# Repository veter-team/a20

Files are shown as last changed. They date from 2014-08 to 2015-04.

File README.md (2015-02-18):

a20
===

Robot for PiWars competition: http://piwars.org

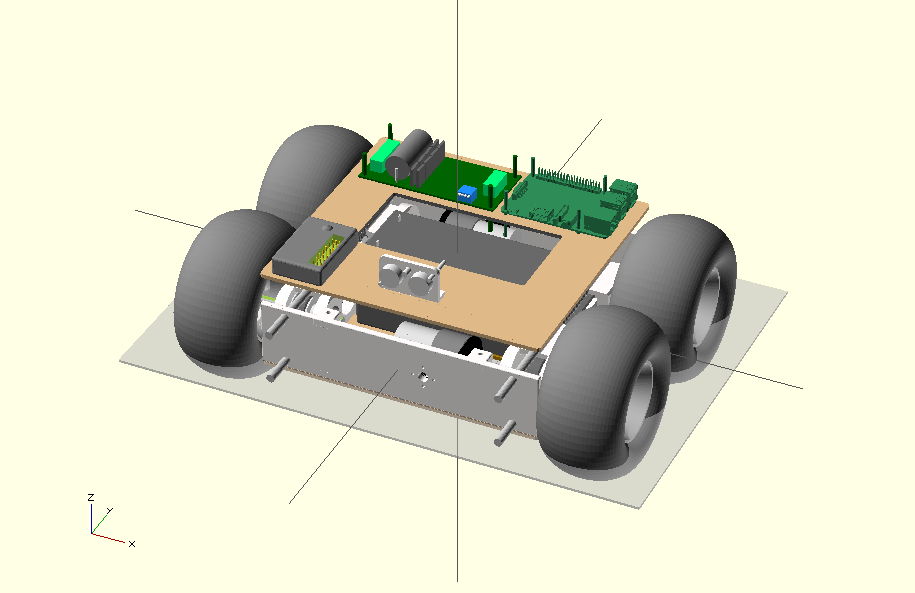
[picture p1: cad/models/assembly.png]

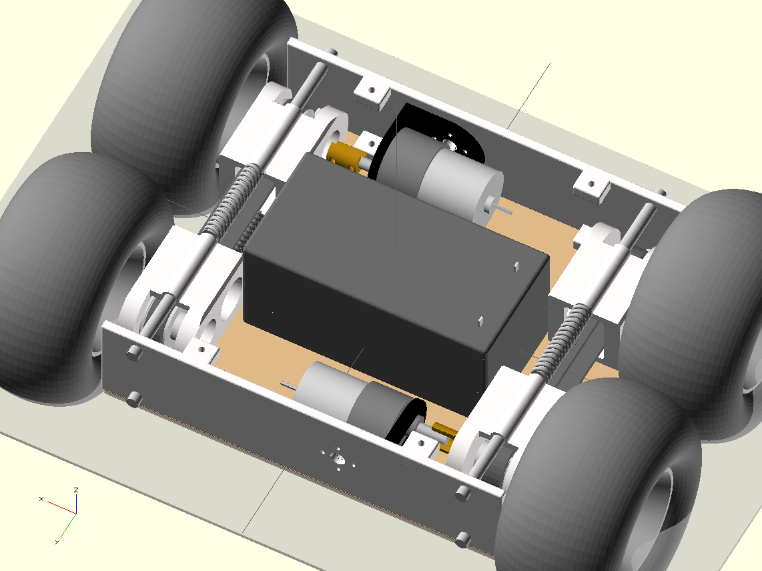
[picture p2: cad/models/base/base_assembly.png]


And here is the video of the first test-drive (RC-controlled): 
http://youtu.be/W47cyLSvp90

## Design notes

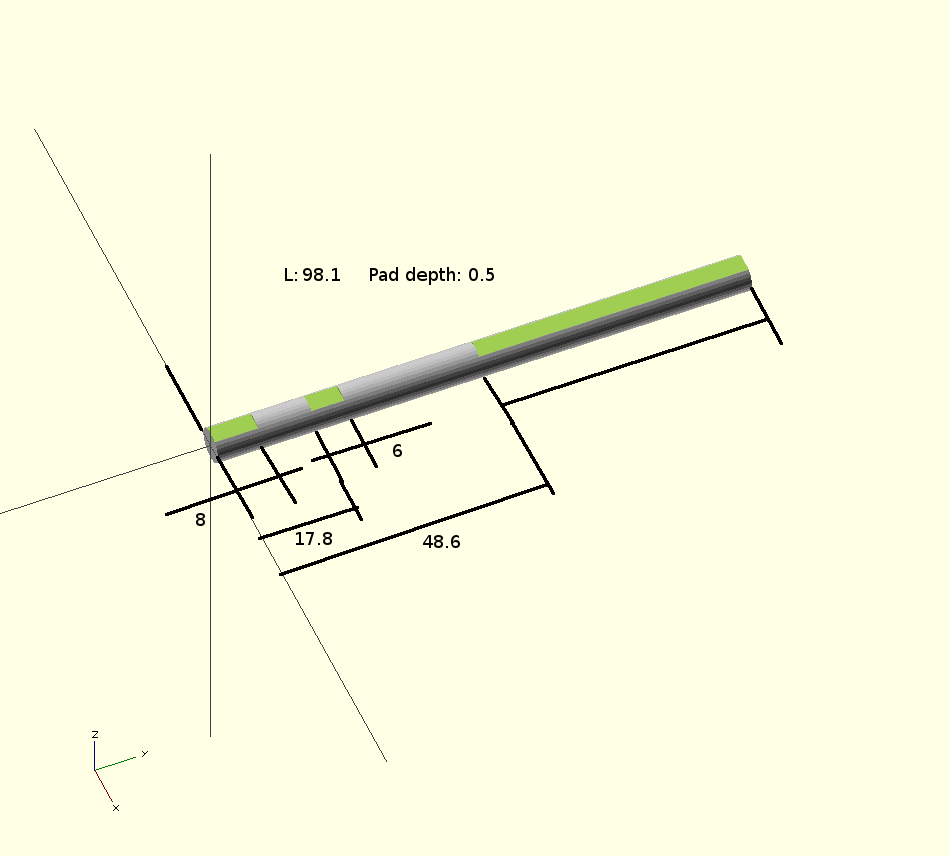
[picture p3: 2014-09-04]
cad/models/base/wheel_shaft.png

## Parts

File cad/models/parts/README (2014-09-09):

STL models of Raspberry Pi B+ are copied from here:
http://www.thingiverse.com/thing:402498/#files
They are included for convenience.

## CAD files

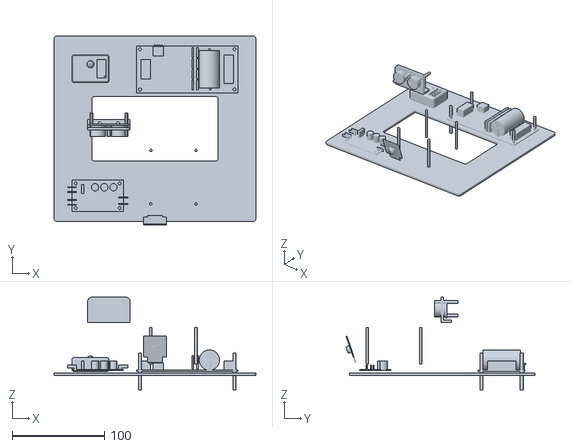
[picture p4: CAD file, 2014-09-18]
cad/models/deck2/stl/deck2_assembly.stl
219.2 x 205.4 x 100.8

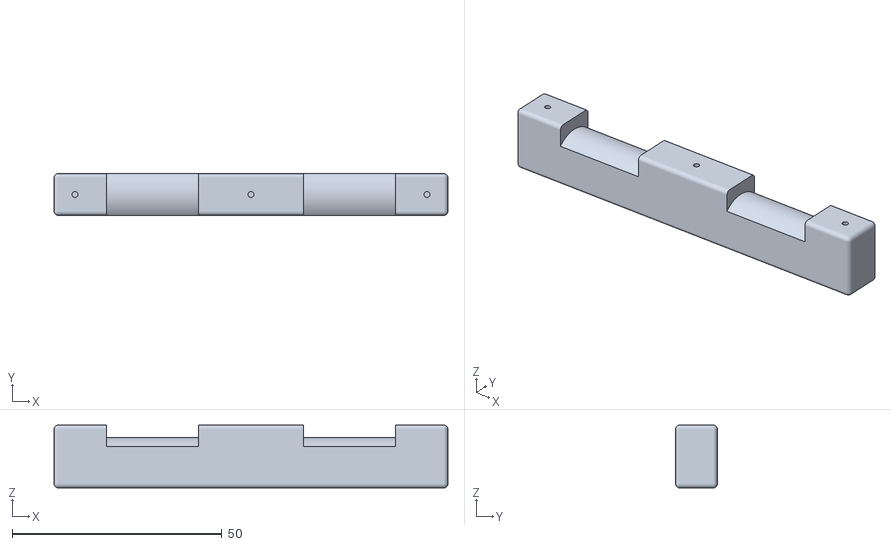
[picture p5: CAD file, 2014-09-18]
cad/for3dprint/base/bottom_battery_holder.stl
94.0 x 10.0 x 15.0

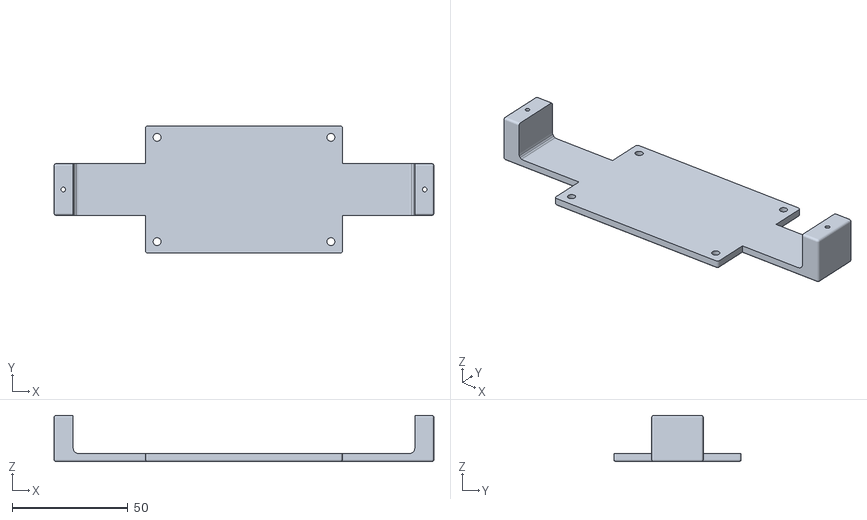
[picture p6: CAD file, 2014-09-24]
cad/for3dprint/deck2/iface_board_holder.stl
164.0 x 55.0 x 20.0

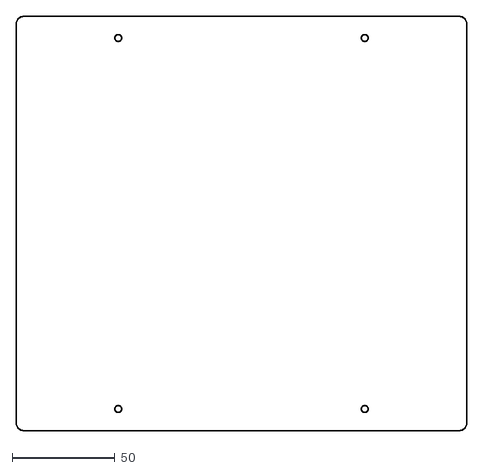
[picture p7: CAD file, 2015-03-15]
cad/forcutting/base1.dxf
219.2 x 201.6

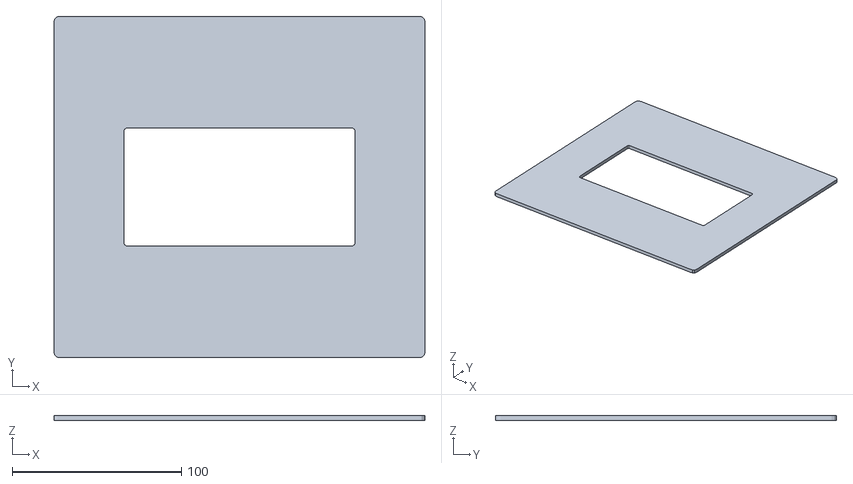
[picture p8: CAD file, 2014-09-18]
cad/models/base/stl/base2.stl
219.2 x 201.6 x 3.00

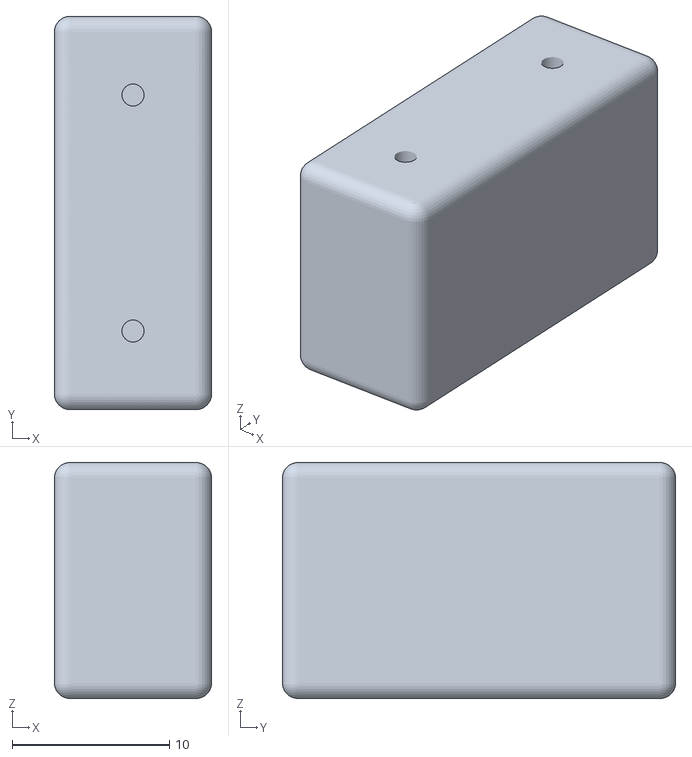
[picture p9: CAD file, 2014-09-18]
cad/for3dprint/base/bottom_battery_stopper.stl
10.0 x 25.0 x 15.0

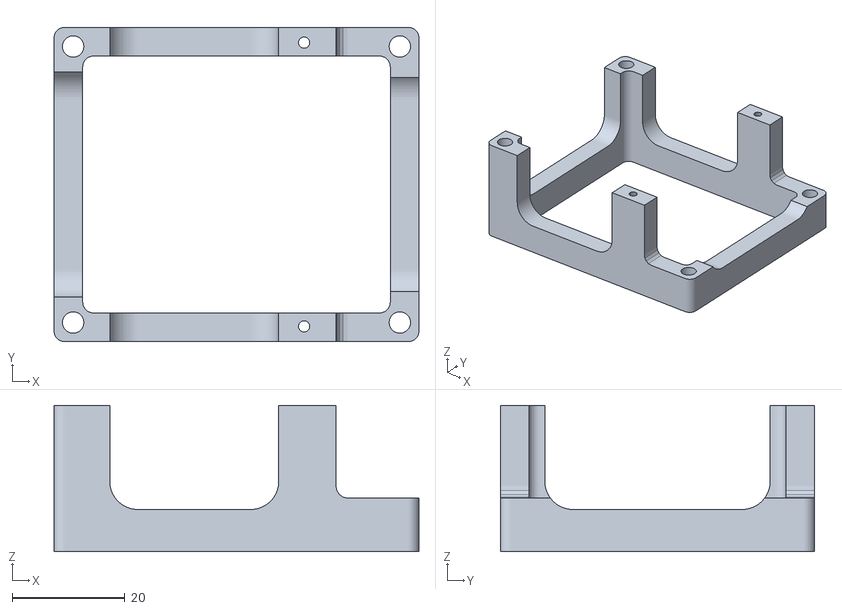
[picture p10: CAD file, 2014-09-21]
cad/for3dprint/deck2/rpi_holder.stl
64.8 x 55.8 x 26.0

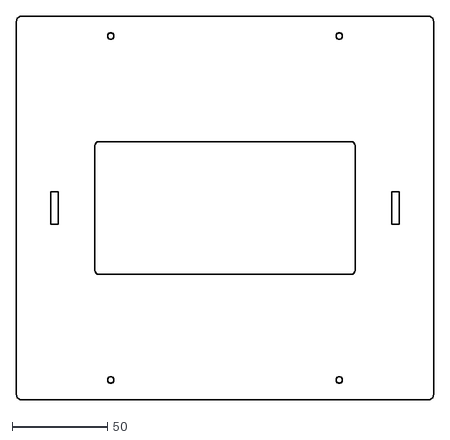
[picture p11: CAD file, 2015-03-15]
cad/forcutting/base2.dxf
219.2 x 201.6

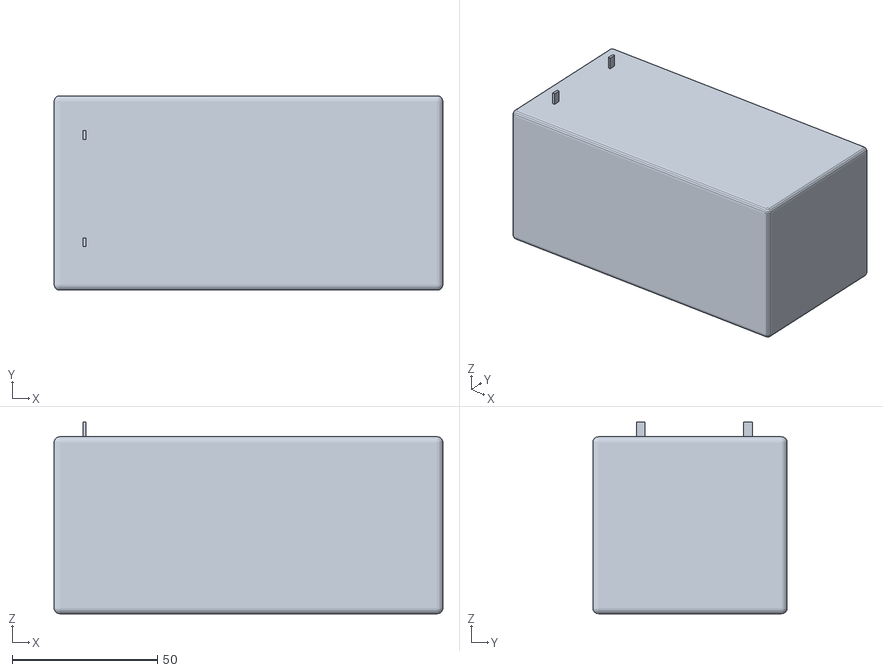
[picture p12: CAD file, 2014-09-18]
cad/models/base/stl/lead_battery.stl
134.0 x 67.0 x 66.0

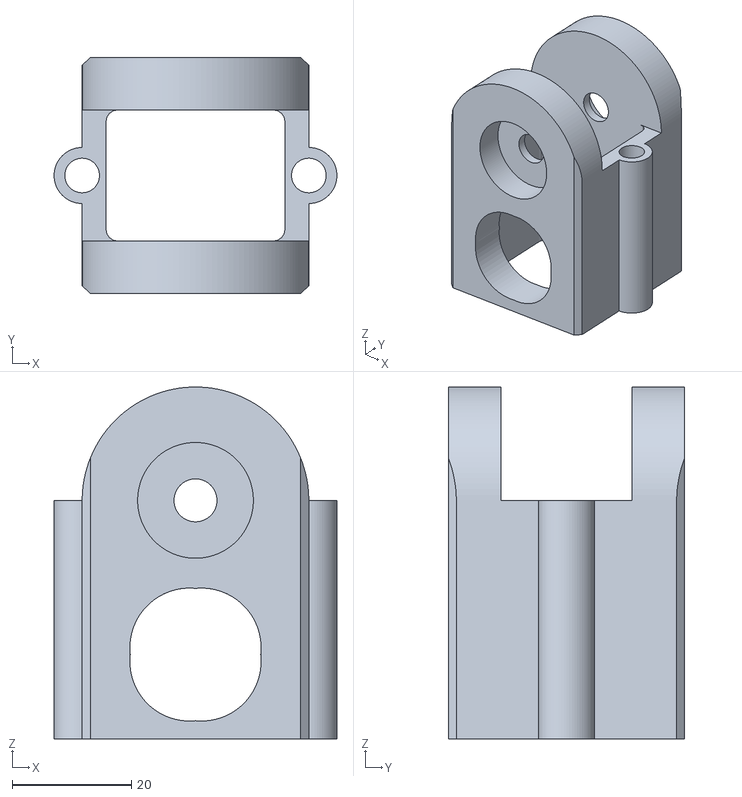
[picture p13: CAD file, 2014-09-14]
cad/for3dprint/base/wheel_holder.stl
47.4 x 39.6 x 59.0

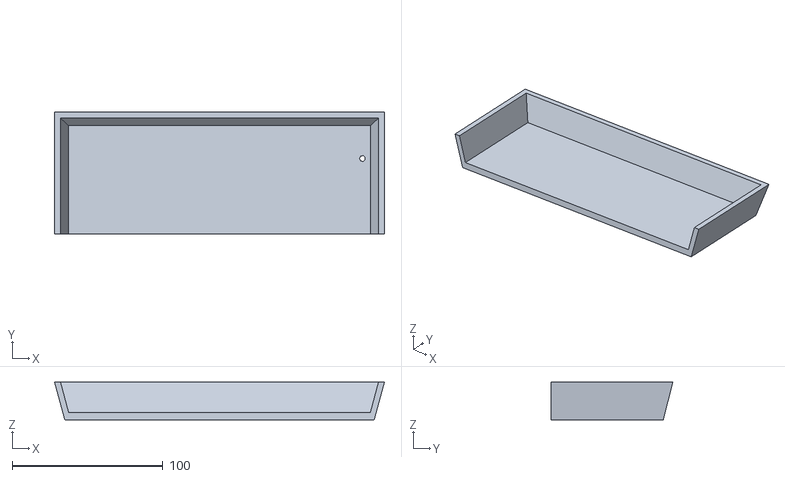
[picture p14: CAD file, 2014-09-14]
cad/for3dprint/deck2/cover2.stl
219.2 x 80.8 x 25.0

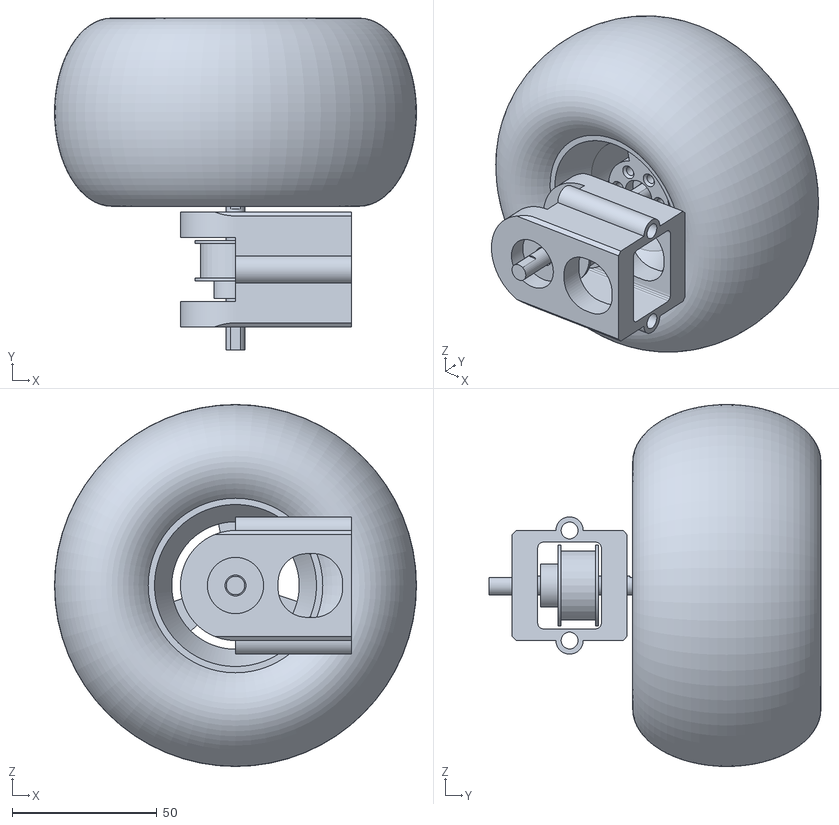
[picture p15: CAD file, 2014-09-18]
cad/models/base/stl/wheel_block.stl
125.0 x 114.6 x 125.0

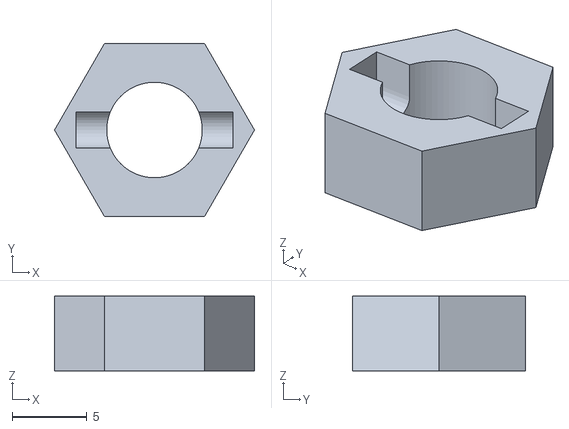
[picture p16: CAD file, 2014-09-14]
cad/for3dprint/base/wheel_clutch.stl
13.4 x 11.6 x 5.00

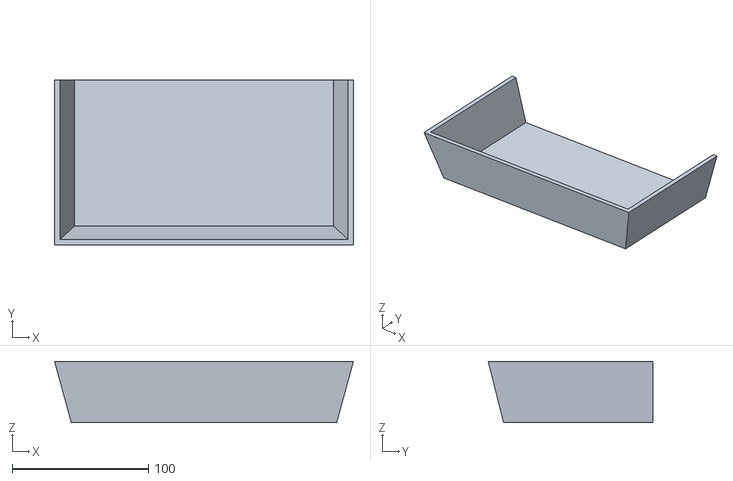
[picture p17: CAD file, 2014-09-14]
cad/for3dprint/deck2/cover1.stl
219.2 x 120.8 x 45.0

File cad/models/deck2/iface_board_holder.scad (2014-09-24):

use <../MCAD/boxes.scad>
include <../main_dimensions.scad>
use <../base/lead_battery.scad>

pad_x_dim = 85;
pad_y_dim = 55;
base_box_dim = [akku_x_dim + 30, akku_y_dim / 3, 20];


module m_hole()
{
    translate([pad_x_dim / 2 - 5, pad_y_dim / 2 - 5, base_box_dim[2] - 4.1])
    mounting_hole(5, false, $fn = 64);
}


module screw_hole()
{
    translate([base_box_dim[0] / 2 - 4, 0, -0.1])
    cylinder(r = 1, h = base_box_dim[2] + 0.3, $fn = 64);
}


module iface_board_holder()
{
    difference()
    {
        union()
        {
            translate([0, 0, 20 / 2])
            roundedBox(base_box_dim, 1, false, $fn = 64);
            
            translate([0, 0, 20 / 2])
            roundedBox([pad_x_dim, pad_y_dim, 20], 1, false, $fn = 64);
        }
        
        // Battery
        translate([0, 0,
                -wheel_holder_z_dim / 2 - shaft_radius - 2 + base_z_size / 2
                - (wheel_holder_z_dim / 2 + shaft_radius + 2 + base_z_size / 2 + 1)])
        scale([1.1, 1.04, 1.08])
        lead_battery();

        m_hole();
        mirror([0, 1, 0])
        m_hole();
        mirror([1, 0, 0])
        {
            m_hole();
            mirror([0, 1, 0])
            m_hole();
        }

        screw_hole();
        mirror([1, 0, 0])
        screw_hole();
    }
    
}


if(ASSEMBLY == undef || ASSEMBLY == 0)
{
    translate([0, 0, base_box_dim[2]])
    rotate([180, 0, 0])
    iface_board_holder();
}

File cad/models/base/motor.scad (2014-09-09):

include <../main_dimensions.scad>

// http://www.pololu.com/product/1442

module motor()
{
    motor_r1 = 36.8 / 2;
    motor_l1 = 22;
    motor_r2 = 33 / 2;
    motor_l2 = 30;

    // back shaft
    color("Silver")
    translate([0, 0, -motor_l1 - motor_l2 - 3 - 10])
    cylinder(h = 12, r = 2 / 2);
    // back shaft holder
    color("LightGray")
    translate([0, 0, -motor_l1 - motor_l2 - 3], $fn = 64)
    cylinder(h = 3, r = 9 / 2);
    // thin back part
    color("LightGray")
    translate([0, 0, -motor_l1 - motor_l2])
    cylinder(h = motor_l2, r = motor_r2, $fn = 128);
    // thick front part
    color("Gray")
    translate([0, 0, -motor_l1])
    cylinder(h = motor_l1, r = motor_r1, $fn = 128);
    translate([motor_shaft_shift, 0, 0])
    {
        // front shaft holder
        color("Gray")
        cylinder(h = 6.5, r = 6, $fn = 64);
        // front shaft
        color("Silver")
        cylinder(h = 22, r = 3, $fn = 64);
    }
}

if(ASSEMBLY == undef || ASSEMBLY == 0)
{
    motor();
}

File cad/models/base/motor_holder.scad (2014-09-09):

// MMT-03 motor holder
// http://www.lynxmotion.com/images/data/mmt-03.pdf

include <../main_dimensions.scad>

$fn = 64;


module motor_holder_mounting_holes(depth = 50)
{
    translate([24, motor_holder_y_dim / 2, 0])
    {
        cylinder(r = 3.9751, h = depth, center = true);

        for(i = [0 : 360 / 4 : 360])
        {
            rotate([0, 0, i])
            translate([0, 8.3312, 0])
            cylinder(r = 1.1938, h = depth, center = true);
        }
    }
}


module motor_holder()
{
    color("Black")
    translate([0, -motor_holder_y_dim / 2, 0])
    difference()
    {
        union()
        {
            cube([motor_holder_x_dim - motor_holder_y_dim / 2, motor_holder_y_dim, motor_holder_z_dim - motor_holder_y_dim / 2]);
            translate([motor_holder_x_dim - motor_holder_y_dim / 2, motor_holder_y_dim / 2, 0])
            cylinder(r = motor_holder_y_dim / 2, h = motor_holder_z_dim - motor_holder_y_dim / 2);

            translate([0, motor_holder_y_dim / 2, motor_holder_z_dim - motor_holder_y_dim / 2])
            rotate([0, 90, 0])
            cylinder(r = motor_holder_y_dim / 2, h = motor_holder_x_dim - motor_holder_x_dim / 2);
        }
        translate([motor_holder_h, -tolerance, motor_holder_h])
        cube([motor_holder_x_dim, motor_holder_y_dim + 2 * tolerance, motor_holder_z_dim]);

        // Shaft hole
        translate([motor_holder_h / 2, motor_holder_y_dim / 2, 25.0])
        union()
        {
            translate([-motor_holder_h, 0, -14.3 / 2])
            rotate([0, 90, 0])
            cylinder(r = 13 / 2, h = 2 * motor_holder_h);

            cube([2 * motor_holder_h, 13, 14.3], center = true);

            translate([-motor_holder_h, 0, 14.3 / 2])
            rotate([0, 90, 0])
            cylinder(r = 13 / 2, h = 2 * motor_holder_h);
        }

        // Motor mounting holes
        translate([motor_holder_h / 2, motor_holder_y_dim / 2, 25.0])
        for(i = [0 : 360 / 6 : 360])
        {
            rotate([i, 0, 0])
            translate([0, 31 / 2, 0])
            rotate([0, 90, 0])
            cylinder(r = 3.3 / 2, h = 50, center = true);
        }

        motor_holder_mounting_holes(3 * motor_holder_h);
    }
}

if(ASSEMBLY == undef || ASSEMBLY == 0)
{
  motor_holder();
}

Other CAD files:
cad/models/base/stl/base1.stl
cad/for3dprint/base/front_pannel.stl
cad/models/base/wheel.scad
cad/models/BezierScad.scad
cad/models/MCAD/boxes.scad
cad/models/MCAD/involute_gears.scad
cad/models/MCAD/metric_fastners.scad
cad/models/MCAD/regular_shapes.scad
cad/models/accessories/ball_collector.scad
cad/models/accessories/ball_collector/assembly.scad
cad/models/accessories/ball_collector/ball_collector.scad
cad/models/accessories/ball_collector/ball_collector_blade.scad
cad/models/accessories/ball_collector/bearing_cover.scad
cad/models/accessories/ball_collector/bearing_stopper.scad
cad/models/accessories/ball_collector/blade_middle.scad
cad/models/accessories/ball_collector/blade_motor_side.scad
cad/models/accessories/ball_collector/blade_nomotor_side.scad
cad/models/accessories/ball_collector/cone_gear.scad
cad/models/accessories/ball_collector/motor_box.scad
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

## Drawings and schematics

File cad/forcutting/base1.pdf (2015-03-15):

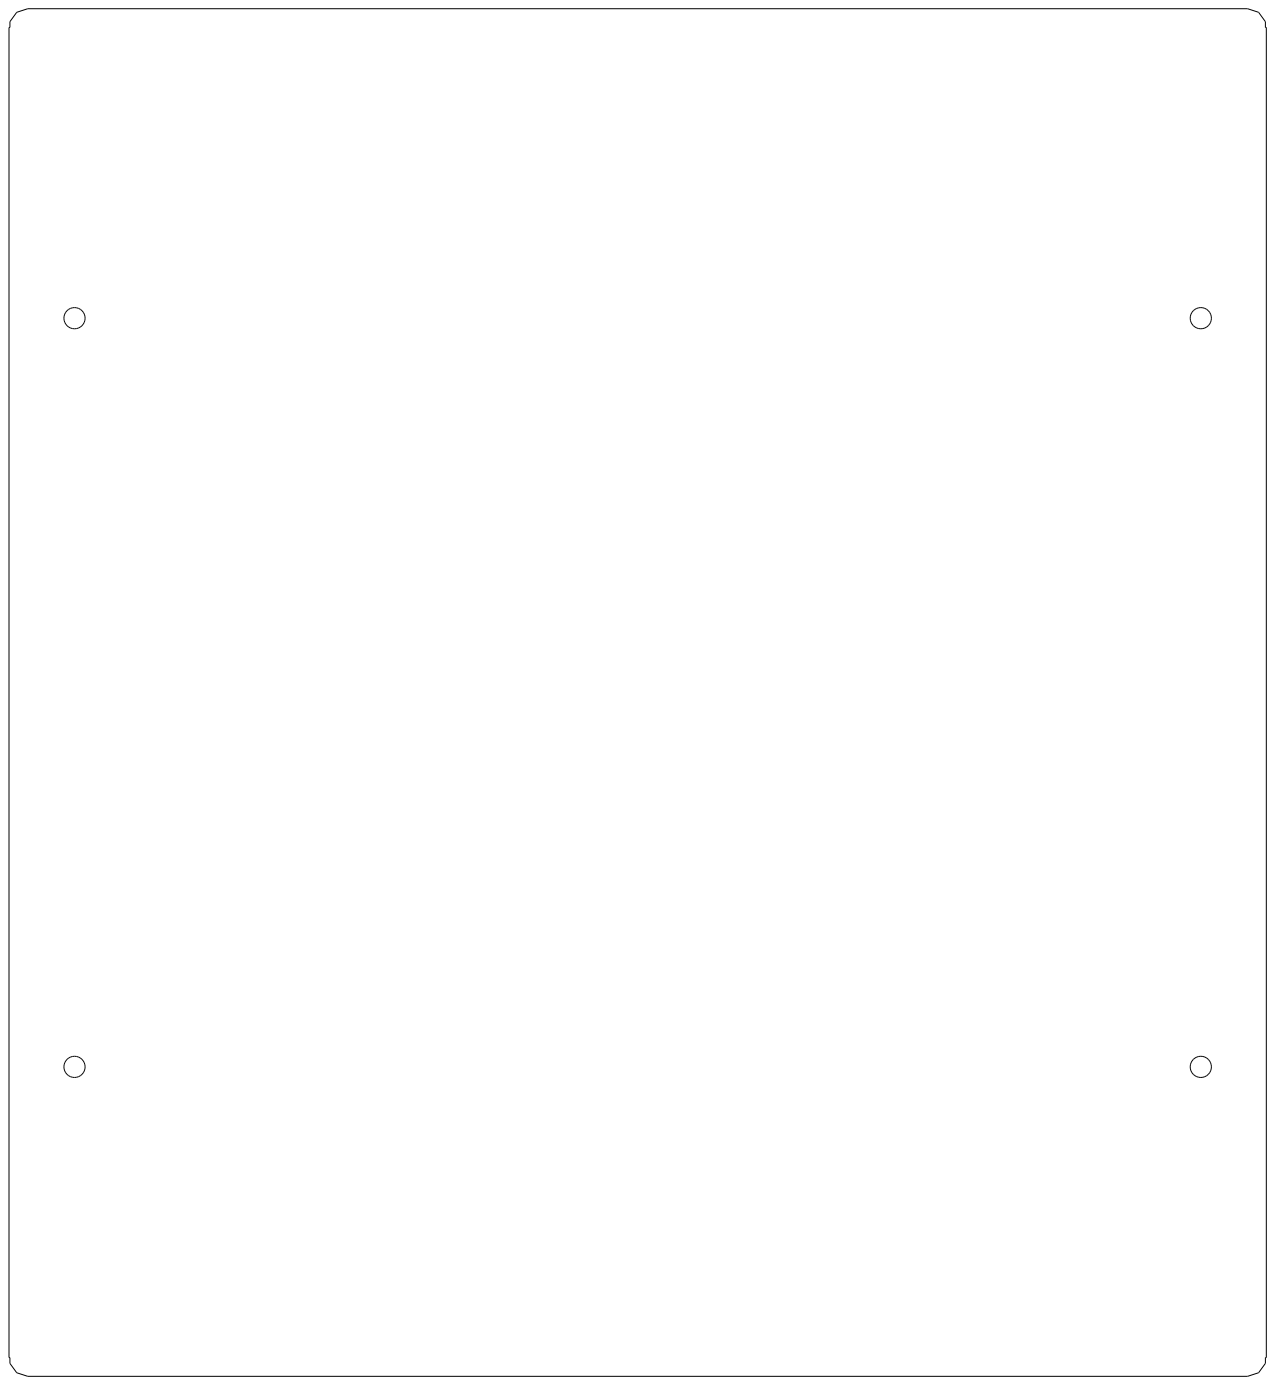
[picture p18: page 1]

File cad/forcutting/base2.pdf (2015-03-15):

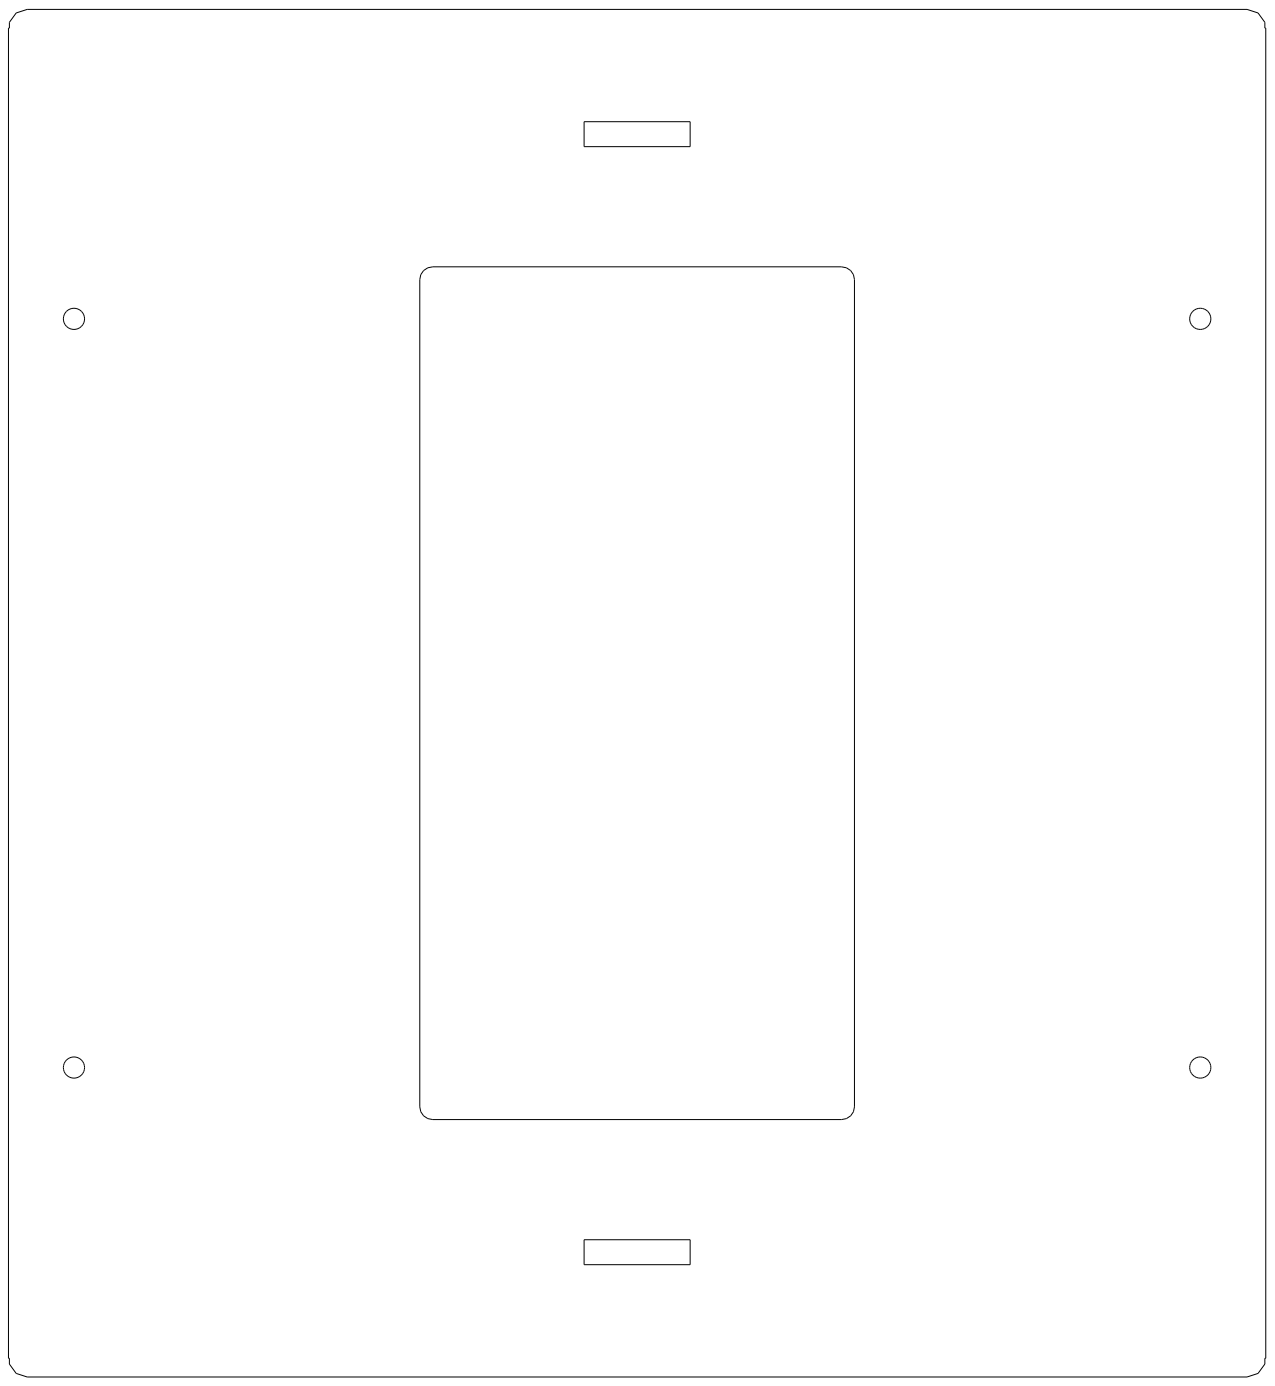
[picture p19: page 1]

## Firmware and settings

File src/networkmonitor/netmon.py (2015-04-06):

#!/usr/bin/env python

# Required python-networkmanager package:
# https://pypi.python.org/pypi/python-networkmanager
# or apt-get install python-networkmanager

"""Listen to StateChanged signal from NetworkManager an
(re)start/stop the application"""

import dbus.mainloop.glib; dbus.mainloop.glib.DBusGMainLoop(set_as_default=True)
from gi.repository import GObject
import NetworkManager
import subprocess
import RPi.GPIO as GPIO

#GPIO.setmode(GPIO.BOARD)
GPIO.setmode(GPIO.BCM)

#status_led = 35
status_led = 19
status_led_on = False
status_led_off = not status_led_on
GPIO.setup(status_led, GPIO.OUT)


# List of programms to execute if/when network connection is changed
commands = ( ['restart', 'locomotion'], 
)


def on_disconnected():
    GPIO.output(status_led, status_led_off)


# Starts processes after network connection changes
def on_connect_global():
    GPIO.output(status_led, status_led_on)
    for p in commands:
        try:
            proc = subprocess.Popen(p)
            #print('Started "{0}" . PID: {1}'.format(' '.join(p), proc.pid))
        except OSError as err:
            print('Could not start "{0}". Error: {1}'.format(' '.join(p), err))


# State handlers table
state_handlers = { NetworkManager.NM_STATE_DISCONNECTED : on_disconnected,
                   NetworkManager.NM_STATE_DISCONNECTING : None,
                   NetworkManager.NM_STATE_ASLEEP : None,
                   NetworkManager.NM_STATE_CONNECTING : None,
                   NetworkManager.NM_STATE_CONNECTED_GLOBAL : on_connect_global
}


# Table to map state id to corresponding text string
state_text = { NetworkManager.NM_STATE_DISCONNECTED : 'disconnected',
               NetworkManager.NM_STATE_DISCONNECTING : 'disconnecting...',
               NetworkManager.NM_STATE_ASLEEP : 'asleep',
               NetworkManager.NM_STATE_CONNECTING : 'connecting...',
               NetworkManager.NM_STATE_CONNECTED_GLOBAL : 'connected'
}


def on_state_changed(newstate):
    #print('Network: {0}'.format(state_text[newstate]))
    # Invoke particular state handler (if not None)
    try:
        handler = state_handlers[newstate]
        if handler is not None:
            handler()
    except KeyError:
        print('No handler for state {0}'.format(state_text[newstate]))


def main():
    # Handle current state
    #on_state_changed(NetworkManager.NetworkManager.State)

    # Register StateChange signal callback
    NetworkManager.NetworkManager.connect_to_signal('StateChanged', on_state_changed)

    # Listen for changes
    loop = GObject.MainLoop()
    try:
        loop.run()
    except KeyboardInterrupt:
        print('Shutting down...')

    # Shut down the application
    #on_state_changed(NetworkManager.NM_STATE_DISCONNECTED)


if __name__ == '__main__':
    main()

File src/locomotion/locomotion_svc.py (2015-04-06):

#!/usr/bin/env python

import sys, traceback
import Ice
import platform
import smbus

Ice.loadSlice('--all -I' + Ice.getSliceDir() + ' -I../interfaces/' + ' ../interfaces/motorcontrol.ice')
Ice.updateModules()
import MotorControl

# See http://www.robot-electronics.co.uk/htm/md22tech.htm
# for more details about controller and i2c interface
class DifferentialSteeringI(MotorControl.DifferentialSteering):

    def __init__(self, logger, bus, addr):
        self.logger = logger
        self.bus = bus
        self.address = addr
        self.operation_mode = 0 # default mode
        self.stopRotation()


    def stopRotation(self):
        self.setOperationMode(4)
        self.bus.write_byte_data(self.address, 1, 128)
        self.bus.write_byte_data(self.address, 2, 128)
        

    def setOperationMode(self, mode):
        if mode != self.operation_mode:
            self.operation_mode = mode
            self.bus.write_byte_data(self.address, 0, mode)


    def getInfo(self, current=None):
        # Ger firmware revision version from register 7
        version = self.bus.read_byte_data(self.address, 7)
        return 'MD22 @ {0}. Firmware: {1}'.format(platform.node(), version)


    def setMotors(self, speed1, speed2, current=None):
        #self.logger.trace('Info', 'Setting motor: speed1={0} speed2={1}'.format(speed1, speed2))
        self.setOperationMode(0)
        self.bus.write_byte_data(self.address, 1, speed1)
        self.bus.write_byte_data(self.address, 2, speed2)
        #self.bus.write_word_data(self.address, 1, (speed1 << 8) + speed2)


    def setMotorsWithTurn(self, speed, turn, current=None):
        #self.logger.trace('Info', 'Setting motor: speed={0} turn={1}'.format(speed, turn))
        self.setOperationMode(4)
        self.bus.write_byte_data(self.address, 1, speed)
        self.bus.write_byte_data(self.address, 2, turn)
        #self.bus.write_word_data(self.address, 1, (speed << 8) + turn)


class LocomotionServer(Ice.Application):
    def run(self, args):
        if len(args) > 1:
            print(self.appName() + ': too many arguments')
            return 1

        logger = self.communicator().getLogger()
        bus = smbus.SMBus(1)
        diff_steering = DifferentialSteeringI(logger, bus, 0xB0 >> 1)

        try:

            adapter = self.communicator().createObjectAdapter('locomotion')
            adapter.add(diff_steering, 
                        self.communicator().stringToIdentity('diffsteering'))
            adapter.activate()
            logger.trace('Info', '{0} - initialized'.format(diff_steering.getInfo()))
            self.communicator().waitForShutdown()

        except EnvironmentError as errinfo:
            errno, errorstring = errinfo
            logger.error('LocomotionServer.run() - error {0}: {1}'.format(errno, errorstring))
        except Ice.Exception as ex:
            logger.error(str(ex))

        diff_steering.stopRotation()

        logger.trace('Info', 'Shutting down...')
        return 0


app = LocomotionServer()
app.main(sys.argv, 'locomotion_server.config')

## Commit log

2014-08-20 Add make-based generation of stl files for 3d printing
    [rim.stl]
2014-08-20 Fix the bug in Makefile
    [motor_holder.stl, rim.stl, wheel_holder.stl]
2014-08-20 Add first version of the camera module model.
    [rpicamera.scad]
2014-08-20 Add rough model of the oled display.
    [oled_display.scad]
2014-08-20 Made shaft holder shorter and walls thinner
    [rim.scad, rim.stl]
2014-08-21 Add just a very first ideas regarding the box around chassis.
    [assembly.scad, base.scad, tower.scad]
2014-08-24 Rotate platform. Redesign belt gear mounting.
    [assembly.scad, base.scad, belt.scad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]
2014-08-24 Add stl file for complete vehicle.
2014-08-28 Old wheel holders does not work. Here is the new idea.
    [assembly.scad, belt.scad, belt_gear_10.scad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]
2014-08-31 Redesigned motor holder
    [assembly.scad, base.scad, front_pannel.scad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]
2014-09-01 Generate STL files for printing and remove outdated models
    [bearing_pad.scad, bearing_pad.stl, front_pannel.stl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]
2014-09-01 Add motor mounting holes
    [front_pannel.scad]
2014-09-01 Regenerate front pannel stl file
    [front_pannel.stl]
2014-09-01 Add missing Use statement for motor holder
    [front_pannel.scad]
2014-09-01 Correct wrong placement of front pannel
    [assembly.scad, main_dimensions.scad]
2014-09-01 Add picture of the base assembly
2014-09-01 Add wheel shaft
    [assembly.scad, main_dimensions.scad, rim.scad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]
2014-09-02 Add first version of motor control server
2014-09-04 Add i2c commands for real hardware
2014-09-04 Make anti-slip pads on wheel shaft
    [wheel_motor_block.scad]
2014-09-05 IceStorm-capable syslog sensor implementation
2014-09-09 Restructure directory tree and prepare for deck2 design
    [assembly.scad, base.scad, base_assembly.scad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]
2014-09-10 Add RC receiver and update deck2 placement
    [assembly.scad, base.scad, base_assembly.scad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]
2014-09-10 Add immage of main assembly
2014-09-10 Add image of main assembly
2014-09-10 Move ready-made parts to parts folder
    [deck2_assembly.scad, md22.scad, rcreceiver.scad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]
2014-09-10 Add camera to assembly. Update RC receiver.
    [deck2_assembly.scad, rcreceiver.scad]
2014-09-10 Fix the problem with relative paths to parts
    [assembly.scad, deck2_assembly.scad]
2014-09-10 Add wheel clutch model
    [wheel_clutch.scad, wheel_clutch.stl]
2014-09-14 Add deck 2 cover
    [assembly.scad, base_assembly.scad, cover1.scad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]
2014-09-14 Add PicoUPS module
    [cover1.scad, cover2.scad, deck2_assembly.scad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]
2014-09-14 Minor color changes
    [deck2_assembly.scad]
2014-09-15 Add test client for syslog sensor server
2014-09-18 Generate STL files for main components
    [base1.stl, base2.stl, cover1.stl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]
2014-09-18 Remove outdated or duplicated STLs
    [cover1.stl, cover2.stl]
2014-09-18 Add battery holders for deck 1
    [base_assembly.scad, bottom_battery_holder.scad, bottom_battery_holder.stl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]
2014-09-21 Add RPi holder
    [base_assembly.scad, deck2_assembly.scad, rpi_holder.scad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]
2014-09-24 Try the new interface board holder idea
    [iface_board_holder.scad, iface_board_holder.stl]
2014-10-12 Start working on ball collector mechanics
    [BezierScad.scad, assembly.scad, ball_collector.scad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]
2014-10-14 Improve first curve calculation
    [ball_collector.scad]
2014-10-15 Further development
    [ball_collector.scad]
2014-10-18 Add motor box
    [ball_collector.scad]
2014-10-18 Add coupling cover and bearing pocket
    [ball_collector.scad]
2014-10-29 New version of the ball collector
    [assembly.scad, ball_collector.scad, ball_collector_blade.scad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]
2014-10-30 Adjust motor box
    [assembly.scad, cone_gear.scad, motor_box.scad]
2014-11-02 Continue working on ball collector blade
    [assembly.scad, ball_collector_blade.scad, cone_gear.scad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]
2014-11-04 Make motor mounting holes on the blade
    [assembly.scad, ball_collector_blade.scad, motor_box.scad]
2014-11-06 Add bearing covers
    [assembly.scad, ball_collector_blade.scad]
2014-11-09 Prepare blade parts for printing
    [blade_middle.scad, blade_motor_side.scad, blade_nomotor_side.scad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]
2014-11-24 Add bearing stopper
    [ball_collector_blade.scad]
2014-11-26 Create separate file for bearing cover
    [bearing_cover.scad]
2014-11-27 Extract bearing stopper in separate file
    [ball_collector_blade.scad, bearing_stopper.scad]
2014-11-27 Improve bearing stopper
    [ball_collector_blade.scad, bearing_stopper.scad]
2014-11-27 Do not need to subtract tolerance from length
    [bearing_stopper.scad]
2015-02-22 Start developing motor-control cockpit component
2015-02-23 First implementation of motor control widget
2015-03-15 Prepare base plates for laser cutting
    [base.scad, base1.dxf, base2.dxf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]
2015-03-16 Add battery holder belt pockets to the base2
    [base.scad, bottom_battery_holder.scad, main_dimensions.scad]
2015-03-27 Add tolerances to sonar holder
    [srf08holder.scad]
2015-04-06 Add status LED signalling
2015-04-06 Remove SSL endpoints. Improve error handling
    [locomotion_svc.py, testclient.py]
2015-04-23 Add remote invocations for motor control
